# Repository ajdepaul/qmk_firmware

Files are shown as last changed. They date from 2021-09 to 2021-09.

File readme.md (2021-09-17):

# Custom 14x5 Keyboard QMK Fork

Forked from: https://github.com/qmk/qmk_firmware

I followed [this](https://github.com/ruiqimao/keyboard-pcb-guide) guide to design the PCB.

- KiCad PCB files can be found in the [pcb](pcb) directory.
- KiCad PCB files for a switch plate can found in the [plate](plate) directory.
- Laser cut case files can be found in the [case](case) directory.

Build with QMK CLI: `qmk compile -kb kb -km default`

Notes:
- I did not originally design the PCB with holes for screws. I ended up drilling
  holes in the PCB in safe locations for screws. The screw holes in the acrylic
  case cutouts line up with the holes that I drilled personally. If you want to
  rebuild the board, I recommend adding holes to the PCB and changing the hole
  placements in the acrylic case cutouts to match.
- I did not originally design the PCB with RGB LED strips in mind. The LED strip
  I am using is soldered directly onto some pins of the MCU. If you want RGB LED
  strip support, I recommend adding some soldering points to the PCB.
- I did not fill the PCB for the switch plate with copper, so it flexes a good
  amount. If you want to rebuild the board, I recommend modifying the PCB plate
  and filling it with copper to give a sturdier feel.

## Personal Keyboard Specs

- Switches: Lubed Cherry MX Clear with 62g springs
- Keycaps:
  - [KPrepublic Japanese Root base](https://kprepublic.com/collections/pbt-dye-sub-keycaps/products/kprepublic-139-japanese-root-japan-black-font-language-cherry-profile-dye-sub-keycap-pbt-for-gh60-xd6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)
  - [Muted Copper Koi Fish artisan](https://www.etsy.com/shop/DreamKaps?ref=from_order_confirm_drawer_receipt_modal)
  - Cheap PBT black & gray blanks for modifiers

## Pictures







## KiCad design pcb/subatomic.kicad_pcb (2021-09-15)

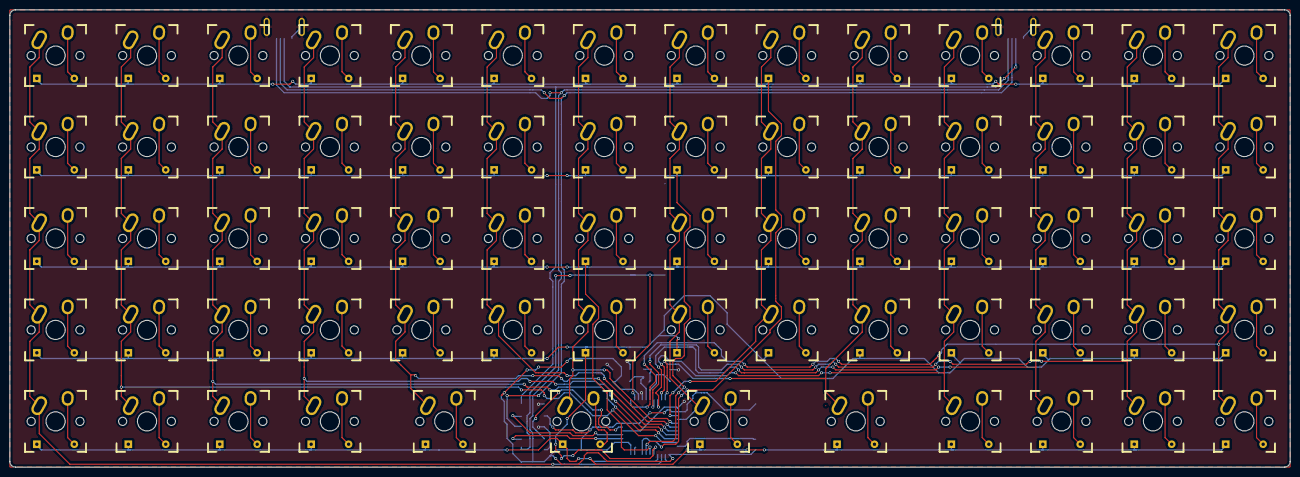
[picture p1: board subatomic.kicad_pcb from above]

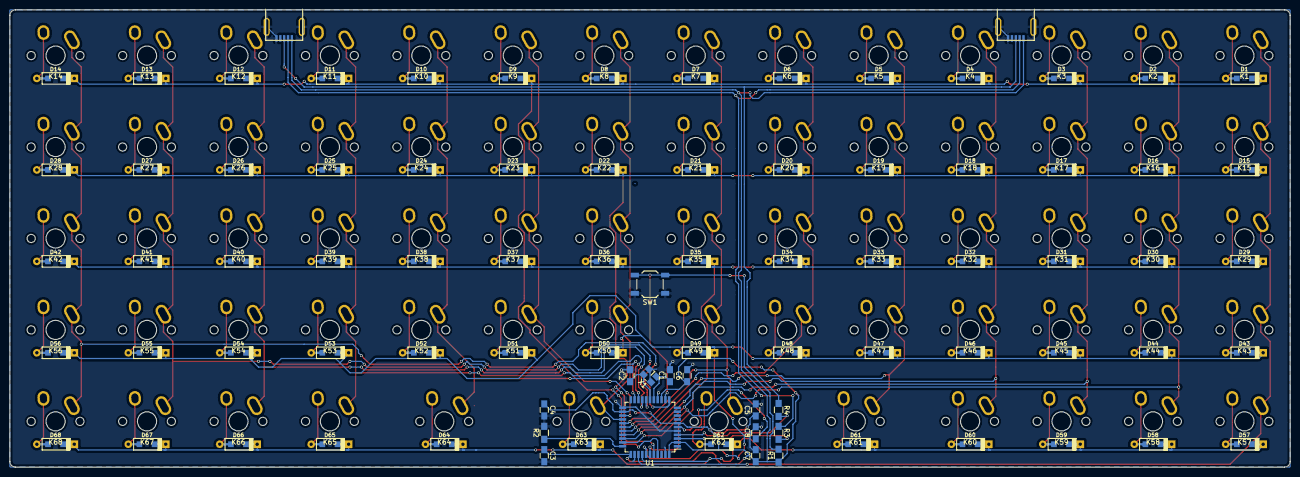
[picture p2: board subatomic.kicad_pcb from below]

Board: 2 copper layers, 266.7 x 95.3 mm, 153 parts (85 on the bottom side), 98 nets.

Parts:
C1, C2: 22p; C_0805_HandSoldering
C3, C4, C5, C6: 0.1u; C_0805_HandSoldering
C7: 4.7u; C_0805_HandSoldering
C8: 1u; C_0805_HandSoldering
D1, D2, D3, D4, D5, D6, D7, D8, D9, D10, D11, D12, D13, D14, D15, D16, D17, D18, D19, D20, D21, D22, D23, D24, D25, D26, D27, D28, D29, D30, D31, D32, D33, D34, D35, D36, D37, D38, D39, D40, D41, D42, D43, D44, D45, D46, D47, D48, D49, D50, D51, D52, D53, D54, D55, D56, D57, D58, D59, D60, D61, D62, D63, D64, D65, D66, D67, D68: D; D_SOD123_axial
J1, J2: USB_mini_micro_B; USB_miniB_hirose_5S8
K1, K2, K3, K4, K5, K6, K7, K8, K9, K10, K11, K12, K13, K14, K15, K16, K17, K18, K19, K20, K21, K22, K23, K24, K25, K26, K27, K28, K29, K30, K31, K32, K33, K34, K35, K36, K37, K38, K39, K40, K41, K42, K43, K44, K45, K46, K47, K48, K49, K50, K51, K52, K53, K54, K55, K56, K57, K58, K59, K60, K65, K66, K67, K68: KEYSW; Mx_Alps_100
K61, K62, K63, K64: KEYSW; Mx_Alps_150
R1, R2: 10k; R_0805_HandSoldering
R3, R4: 22; R_0805_HandSoldering
SW1: SW_PUSH; SW_SPST_TL3342
U1: ATMEGA32U4; TQFP-44_10x10mm_Pitch0.8mm
X1: XTAL_GND; crystal_FA238-TSX3225

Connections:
/col0: K1.1, K15.1, K29.1, K43.1, K57.1, U1.36
/col1: K2.1, K16.1, K30.1, K44.1, K58.1, U1.32
/col2: K3.1, K17.1, K31.1, K45.1, K59.1, U1.31
/col3: K4.1, K18.1, K32.1, K46.1, K60.1, U1.30
/col4: K5.1, K19.1, K33.1, K47.1, K61.1, U1.29
/col5: K6.1, K20.1, K34.1, K48.1, U1.28
/col6: K7.1, K21.1, K35.1, K49.1, K62.1, U1.27
/col7: K8.1, K22.1, K36.1, K50.1, K63.1, U1.26
/col8: K9.1, K23.1, K37.1, K51.1, U1.25
/col9: K10.1, K24.1, K38.1, K52.1, K64.1, U1.21
/col10: K11.1, K25.1, K39.1, K53.1, K65.1, U1.20
/col11: K12.1, K26.1, K40.1, K54.1, K66.1, U1.19
/col12: K13.1, K27.1, K41.1, K55.1, K67.1, U1.18
/col13: K14.1, K28.1, K42.1, K56.1, K68.1, U1.12
/row0: D1.1, D2.1, D3.1, D4.1, D5.1, D6.1, D7.1, D8.1, D9.1, D10.1, D11.1, D12.1, D13.1, D14.1, U1.41
/row1: D15.1, D16.1, D17.1, D18.1, D19.1, D20.1, D21.1, D22.1, D23.1, D24.1, D25.1, D26.1, D27.1, D28.1, U1.40
/row2: D29.1, D30.1, D31.1, D32.1, D33.1, D34.1, D35.1, D36.1, D37.1, D38.1, D39.1, D40.1, D41.1, D42.1, U1.39
/row3: D43.1, D44.1, D45.1, D46.1, D47.1, D48.1, D49.1, D50.1, D51.1, D52.1, D53.1, D54.1, D55.1, D56.1, U1.38
/row4: D57.1, D58.1, D59.1, D60.1, D61.1, D62.1, D63.1, D64.1, D65.1, D66.1, D67.1, D68.1, U1.37
GND: C1.2, C2.2, C3.2, C4.2, C5.2, C6.2, C7.2, C8.2, J1.5, J1.6, J2.5, J2.6, R2.2, SW1.1, U1.5, U1.15, U1.23, U1.35, U1.43, X1.3
unnamed: C1.1, U1.16, X1.1
unnamed: C2.1, U1.17, X1.2
unnamed: C8.1, U1.6
unnamed: D1.2, K1.2
unnamed: D2.2, K2.2
unnamed: D3.2, K3.2
unnamed: D4.2, K4.2
unnamed: D5.2, K5.2
unnamed: D6.2, K6.2
unnamed: D7.2, K7.2
unnamed: D8.2, K8.2
unnamed: D9.2, K9.2
unnamed: D10.2, K10.2
unnamed: D11.2, K11.2
unnamed: D12.2, K12.2
unnamed: D13.2, K13.2
unnamed: D14.2, K14.2
unnamed: D15.2, K15.2
unnamed: D16.2, K16.2
unnamed: D17.2, K17.2
unnamed: D18.2, K18.2
unnamed: D19.2, K19.2
unnamed: D20.2, K20.2
unnamed: D21.2, K21.2
unnamed: D22.2, K22.2
unnamed: D23.2, K23.2
unnamed: D24.2, K24.2
unnamed: D25.2, K25.2
unnamed: D26.2, K26.2
unnamed: D27.2, K27.2
unnamed: D28.2, K28.2
unnamed: D29.2, K29.2
unnamed: D30.2, K30.2
unnamed: D31.2, K31.2
unnamed: D32.2, K32.2
unnamed: D33.2, K33.2
unnamed: D34.2, K34.2
unnamed: D35.2, K35.2
unnamed: D36.2, K36.2
unnamed: D37.2, K37.2
unnamed: D38.2, K38.2
unnamed: D39.2, K39.2
unnamed: D40.2, K40.2
unnamed: D41.2, K41.2
unnamed: D42.2, K42.2
unnamed: D43.2, K43.2
unnamed: D44.2, K44.2
unnamed: D45.2, K45.2
unnamed: D46.2, K46.2
unnamed: D47.2, K47.2
unnamed: D48.2, K48.2
unnamed: D49.2, K49.2
unnamed: D50.2, K50.2
unnamed: D51.2, K51.2
unnamed: D52.2, K52.2
unnamed: D53.2, K53.2
unnamed: D54.2, K54.2
unnamed: D55.2, K55.2
unnamed: D56.2, K56.2
unnamed: D57.2, K57.2
unnamed: D58.2, K58.2
unnamed: D59.2, K59.2
unnamed: D60.2, K60.2
unnamed: D61.2, K61.2
unnamed: D62.2, K62.2
unnamed: D63.2, K63.2
unnamed: D64.2, K64.2
unnamed: D65.2, K65.2
unnamed: D66.2, K66.2
unnamed: D67.2, K67.2
unnamed: D68.2, K68.2
unnamed: J1.2, J2.2, R3.1
unnamed: J1.3, J2.3, R4.1
unnamed: R1.2, SW1.2, U1.13
unnamed: R2.1, U1.33
unnamed: R3.2, U1.3
unnamed: R4.2, U1.4
VCC: C3.1, C4.1, C5.1, C6.1, C7.1, J1.1, J2.1, R1.1, U1.2, U1.7, U1.14, U1.24, U1.34, U1.44

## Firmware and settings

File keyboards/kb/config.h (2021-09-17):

#ifndef CONFIG_H
#define CONFIG_H

#include "config_common.h"

/* USB Device descriptor parameter */
#define VENDOR_ID       0xFEED
#define PRODUCT_ID      0x6060
#define DEVICE_VER      0x0001
#define MANUFACTURER    qmkbuilder
#define PRODUCT         keyboard
#define DESCRIPTION     Keyboard

/* key matrix size */
#define MATRIX_ROWS 5
#define MATRIX_COLS 14

/* key matrix pins */
#define MATRIX_ROW_PINS { F0, F1, F4, F5, F6 }
#define MATRIX_COL_PINS { F7, C7, C6, B6, B5, B4, D7, D6, D4, D3, D2, D1, D0, B7 }
#define UNUSED_PINS

/* COL2ROW or ROW2COL */
#define DIODE_DIRECTION COL2ROW

/* number of backlight levels */

#ifdef BACKLIGHT_PIN
#define BACKLIGHT_LEVELS 3
#endif

/* Set 0 if debouncing isn't needed */
#define DEBOUNCING_DELAY 5

/* Mechanical locking support. Use KC_LCAP, KC_LNUM or KC_LSCR instead in keymap */
#define LOCKING_SUPPORT_ENABLE

/* Locking resynchronize hack */
#define LOCKING_RESYNC_ENABLE

/* key combination for command */
#define IS_COMMAND() ( \
    keyboard_report->mods == (MOD_BIT(KC_LSHIFT) | MOD_BIT(KC_RSHIFT)) \
)

/* prevent stuck modifiers */
#define PREVENT_STUCK_MODIFIERS

#define RGB_DI_PIN E6
#ifdef RGB_DI_PIN
#define RGBLED_NUM 24

#define RGBLIGHT_SLEEP

#define RGBLIGHT_LIMIT_VAL 255
#define RGBLIGHT_DEFAULT_HUE 0
#define RGBLIGHT_DEFAULT_SAT 255
#define RGBLIGHT_DEFAULT_VAL 255

#define RGBLIGHT_EFFECT_RAINBOW_SWIRL
#define RGBLIGHT_DEFAULT_MODE RGBLIGHT_MODE_RAINBOW_SWIRL + 2

#define RGBLIGHT_LAYERS
#endif

#endif
